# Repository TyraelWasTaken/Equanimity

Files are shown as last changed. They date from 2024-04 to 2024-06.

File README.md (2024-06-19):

# Equanimity
## Equanimity is a 65%, gasket mounted, alice style keyboard with a knob.

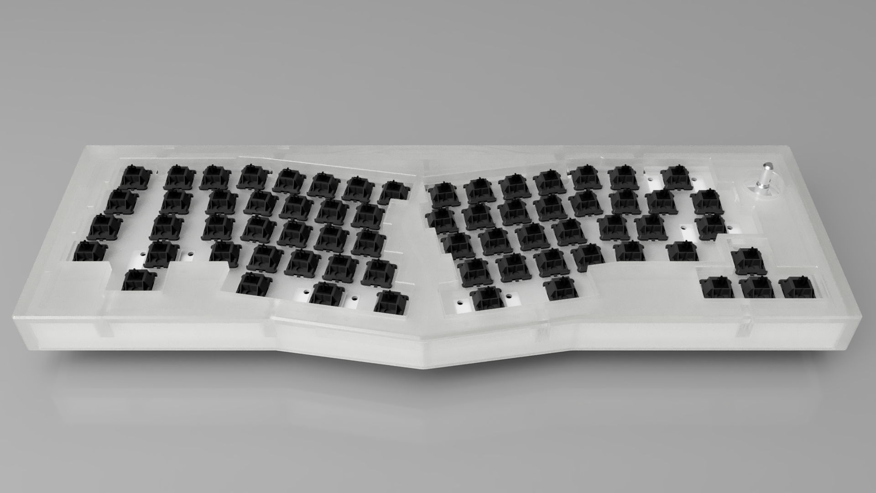
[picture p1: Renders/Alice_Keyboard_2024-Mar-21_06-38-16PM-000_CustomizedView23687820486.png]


There were no design goals for the project, it was simply what I wanted to see in a keyboard.

It is fully Open-Source, all files I have used to make my own I have published for everyone else to enjoy.

Firmware wise, the qmk build *should* be functional, and I am actively working on trying to publish a successful via build.

Equanimity uses cherry switches with kailh hotswap sockets, and the standard EC11 (although an EC12 should work just fine).
Also, the project uses a C series unified daughterboard with JST connectors.

The "symbol" for the equanimity is a water lily.

If you wish to build this or have any inquiries please contact me via discord and I will help you with the project.

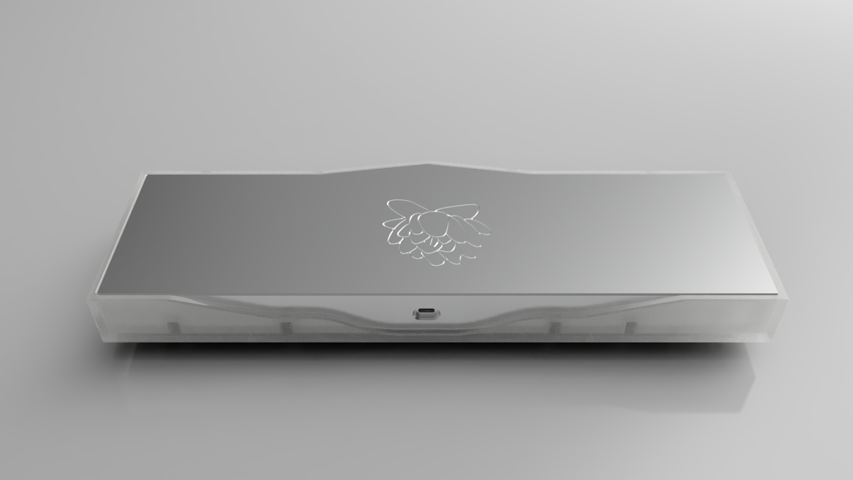
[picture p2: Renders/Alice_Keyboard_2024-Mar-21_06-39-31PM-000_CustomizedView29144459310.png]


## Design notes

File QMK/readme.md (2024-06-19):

# equanimity

equanimity

Arisu-ish Alice keyboard with an EC11 and some accent keys, staggered.

* Keyboard Maintainer: [TyraelWasTaken](https://github.com/TyraelWasTaken)
* Hardware Supported: *UDB C3 or greater with Equanimity PCB, no other PCBs are supported for the case*
* Hardware Availability: *If you wish to build this, all files are available here: https://github.com/TyraelWasTaken/Equanimity*

Make example for this keyboard (after setting up your build environment):

    make TyraelWasTaken/equanimity:default

Flashing example for this keyboard:

    make TyraelWasTaken/equanimity:default:flash

See the [build environment setup](https://docs.qmk.fm/#/getting_started_build_tools) and the [make instructions](https://docs.qmk.fm/#/getting_started_make_guide) for more information. Brand new to QMK? Start with our [Complete Newbs Guide](https://docs.qmk.fm/#/newbs).

## Bootloader

Enter the bootloader in 3 ways:

* **Bootmagic reset**: Hold down the key at (0,0) in the matrix (set as Delete by default) and plug in the keyboard
* **Physical reset button**: Press both the Top and Bottom buttons at the same time
* **Keycode in layout**: Press the key mapped to `RESET` if it is available (this has not been mapped by default)

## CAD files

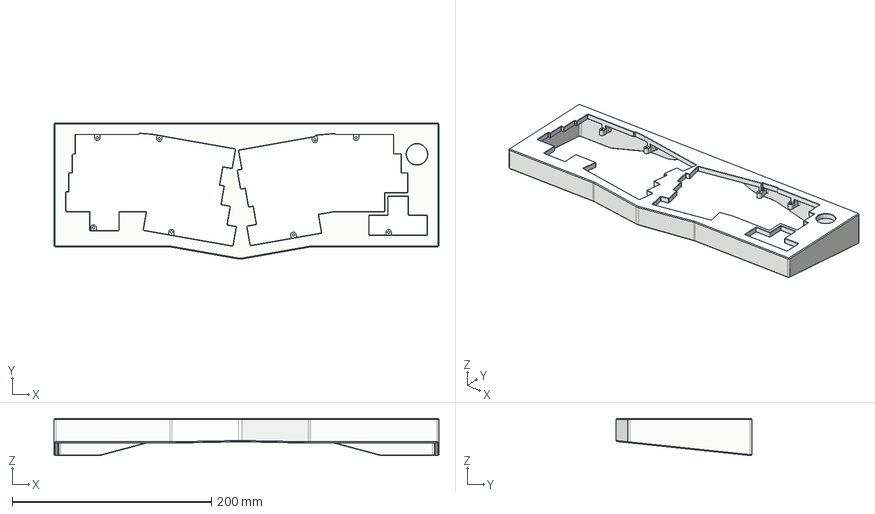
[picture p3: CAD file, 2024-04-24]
Case/Top Case.step
386.9 x 137.1 x 37.6 mm

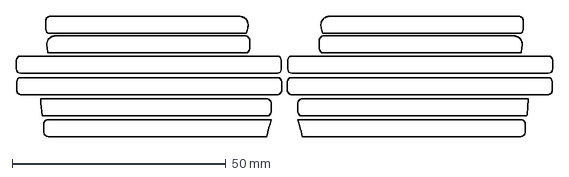
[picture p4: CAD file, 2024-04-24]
Gaskets/Gaskets.dxf
125.5 x 28.1 mm

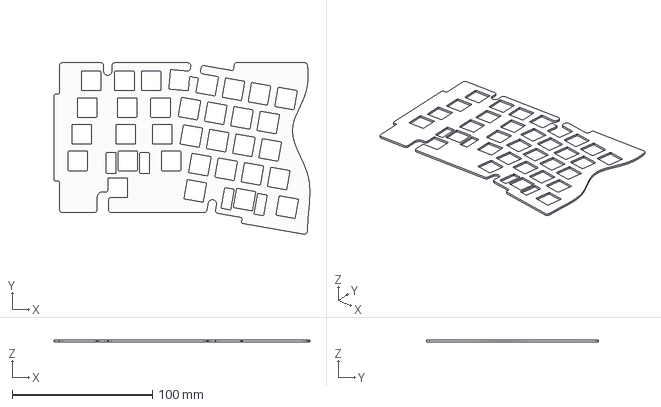
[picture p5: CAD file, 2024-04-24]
Plates/Left Plate.step
182.8 x 122.5 x 1.50 mm

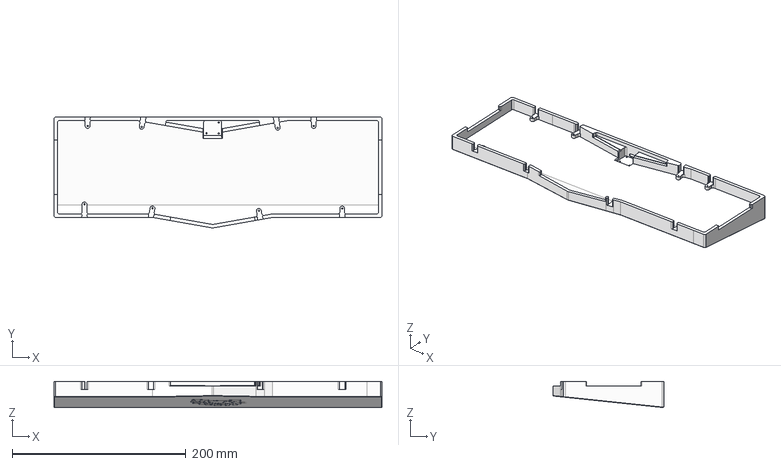
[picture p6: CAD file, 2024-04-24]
Case/Bottom Case.step
377.4 x 127.6 x 30.1 mm

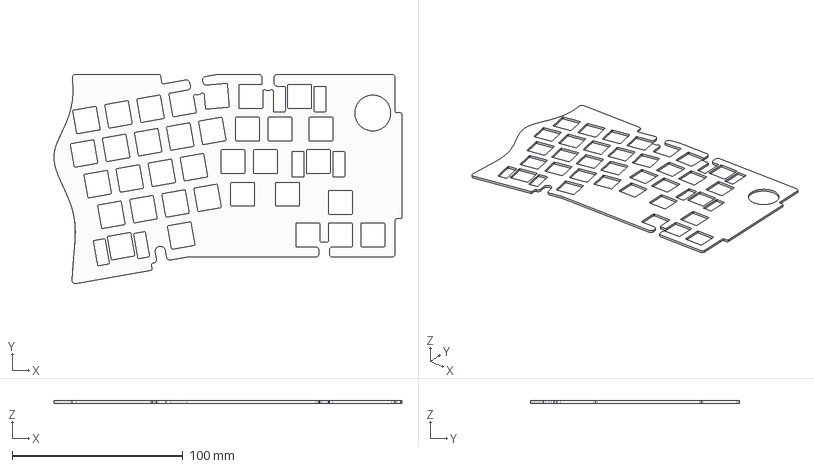
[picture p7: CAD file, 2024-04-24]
Plates/Right plate.step
203.6 x 122.5 x 1.50 mm

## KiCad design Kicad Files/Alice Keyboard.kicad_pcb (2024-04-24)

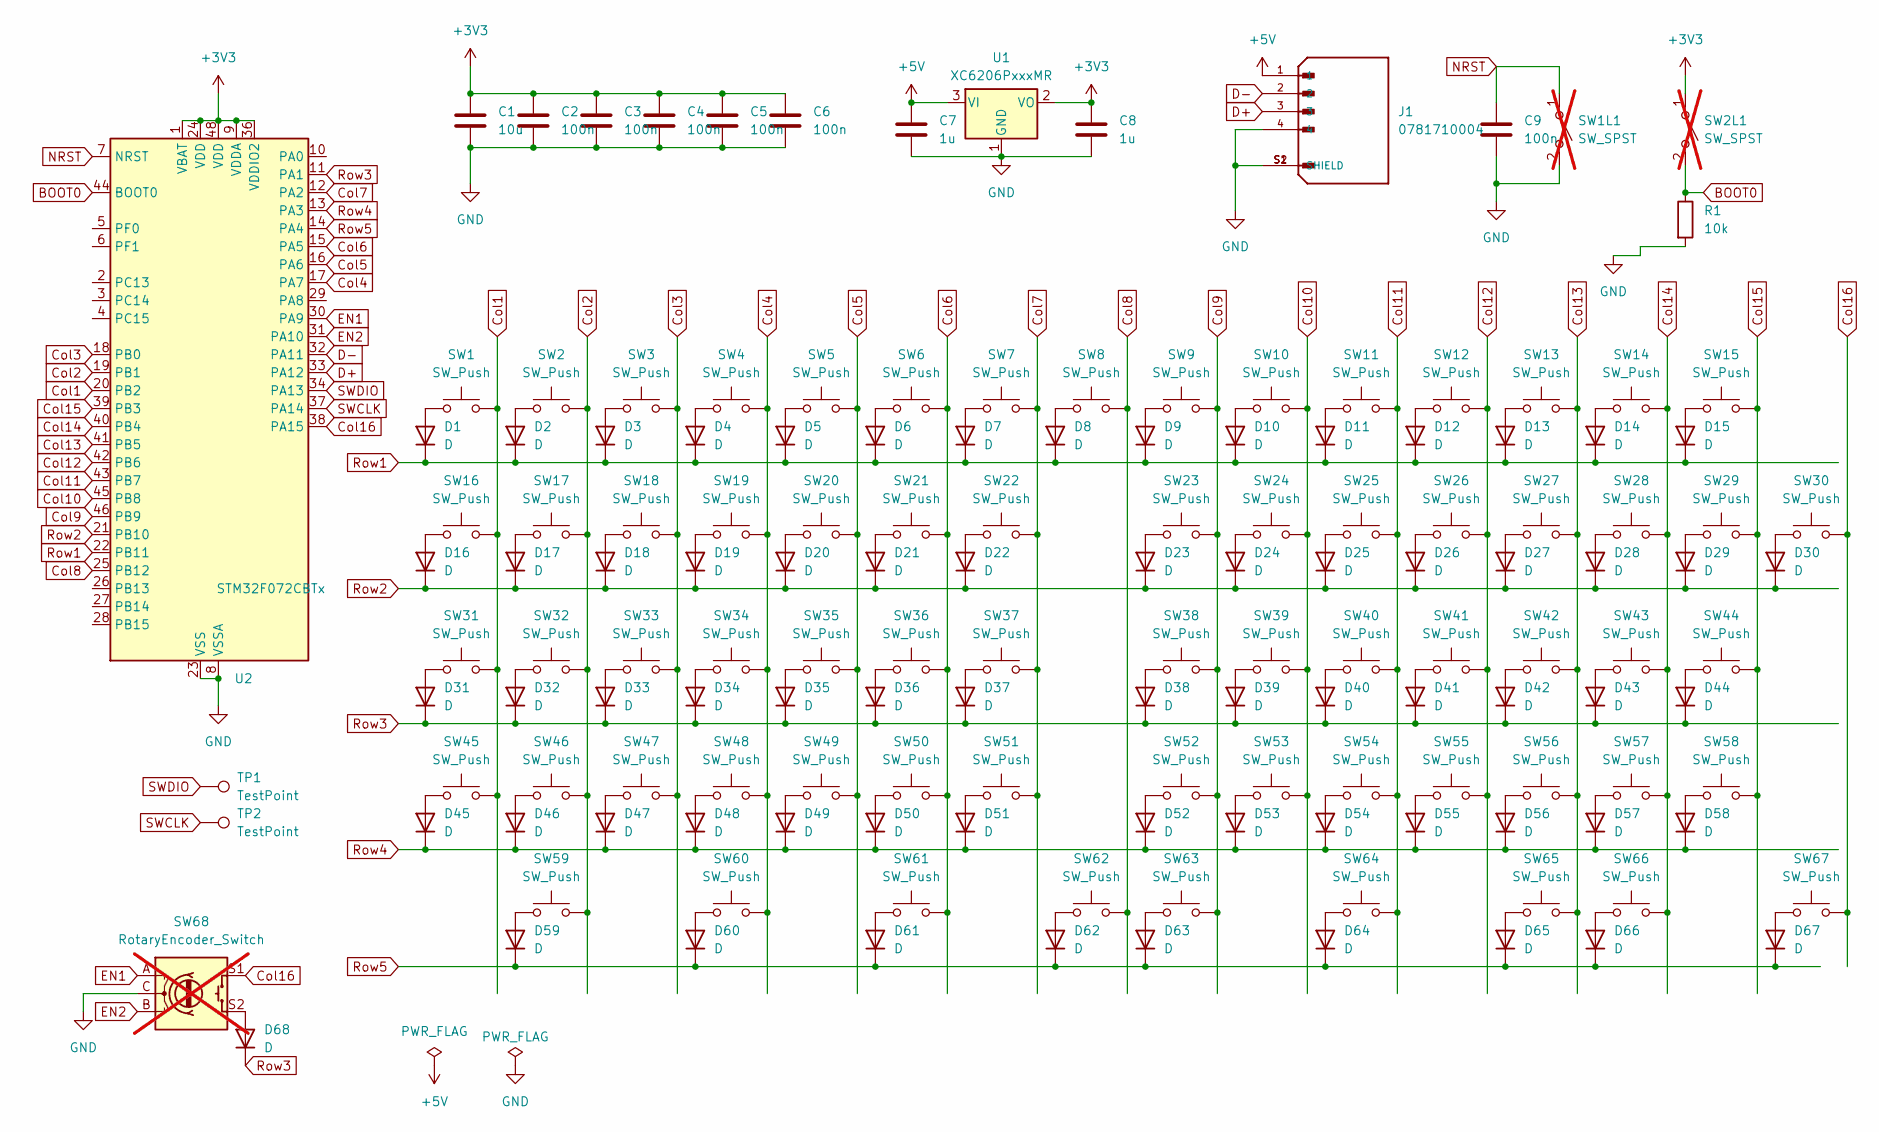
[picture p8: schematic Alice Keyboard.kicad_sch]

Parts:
C1: 10u; C_0805_2012Metric_Pad1.18x1.45mm_HandSolder
C2, C3, C4, C5, C6, C9: 100n; C_0603_1608Metric
C7, C8: 1u; C_0805_2012Metric_Pad1.18x1.45mm_HandSolder
D1, D2, D3, D4, D5, D6, D7, D8, D9, D10, D11, D12, D13, D14, D15, D16, D17, D18, D19, D20, D21, D22, D23, D24, D25, D26, D27, D28, D29, D30, D31, D32, D33, D34, D35, D36, D37, D38, D39, D40, D41, D42, D43, D44, D45, D46, D47, D48, D49, D50, D51, D52, D53, D54, D55, D56, D57, D58, D59, D60, D61, D62, D63, D64, D65, D66, D67, D68: D; D_SOD-123
J1: 0781710004; SM04B-SRSS-TB(LF)(SN); PARTREV G
R1: 10k; R_0805_2012Metric_Pad1.20x1.40mm_HandSolder
SW1, SW2, SW3, SW4, SW5, SW6, SW7, SW8, SW9, SW10, SW11, SW12, SW13, SW14, SW16, SW18, SW19, SW20, SW21, SW22, SW23, SW24, SW25, SW26, SW27, SW28, SW29, SW31, SW33, SW34, SW35, SW36, SW37, SW38, SW39, SW40, SW41, SW42, SW43, SW45, SW47, SW48, SW49, SW50, SW51, SW52, SW53, SW54, SW55, SW56, SW58, SW62, SW65, SW66, SW67: SW_Push; MX-Hotswap-1U
SW1L1, SW2L1: SW_SPST; SW_SPST_SKQG_WithStem; not fitted
SW15: SW_Push; MX-Hotswap-2U
SW17, SW30, SW59, SW60, SW64: SW_Push; MX-Hotswap-1.5U
SW32, SW57: SW_Push; MX-Hotswap-1.75U
SW44, SW46, SW61, SW63: SW_Push; MX-Hotswap-2.25U
SW68: RotaryEncoder_Switch; RotaryEncoder_Alps_EC11E-Switch_Vertical_H20mm; not fitted
TP1, TP2: TestPoint; Pin_D0.7mm_L6.5mm_W1.8mm_FlatFork
U1: XC6206PxxxMR; SOT-23-3
U2: STM32F072CBTx; LQFP-48_7x7mm_P0.5mm

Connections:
+3V3: C1.1, C2.1, C3.1, C4.1, C5.1, C6.1, C8.1, SW2L1.1 (A), U1.2 (VO), U2.1 (VBAT), U2.9 (VDDA), U2.24 (VDD), U2.36 (VDDIO2), U2.48 (VDD)
+5V: C7.1, J1.1, U1.3 (VI)
BOOT0: R1.1, SW2L1.2 (B), U2.44 (BOOT0)
Col1: SW1.2, SW16.2, SW31.2, SW45.2, U2.20 (PB2)
Col2: SW2.2, SW17.2, SW32.2, SW46.2, SW59.2, U2.19 (PB1)
Col3: SW3.2, SW18.2, SW33.2, SW47.2, U2.18 (PB0)
Col4: SW4.2, SW19.2, SW34.2, SW48.2, SW60.2, U2.17 (PA7)
Col5: SW5.2, SW20.2, SW35.2, SW49.2, U2.16 (PA6)
Col6: SW6.2, SW21.2, SW36.2, SW50.2, SW61.2, U2.15 (PA5)
Col7: SW7.2, SW22.2, SW37.2, SW51.2, U2.12 (PA2)
Col8: SW8.2, SW62.2, U2.25 (PB12)
Col9: SW9.2, SW23.2, SW38.2, SW52.2, SW63.2, U2.46 (PB9)
Col10: SW10.2, SW24.2, SW39.2, SW53.2, U2.45 (PB8)
Col11: SW11.2, SW25.2, SW40.2, SW54.2, SW64.2, U2.43 (PB7)
Col12: SW12.2, SW26.2, SW41.2, SW55.2, U2.42 (PB6)
Col13: SW13.2, SW27.2, SW42.2, SW56.2, SW65.2, U2.41 (PB5)
Col14: SW14.2, SW28.2, SW43.2, SW57.2, SW66.2, U2.40 (PB4)
Col15: SW15.2, SW29.2, SW44.2, SW58.2, U2.39 (PB3)
Col16: SW30.2, SW67.2, SW68.S1, U2.38 (PA15)
D+: J1.3, U2.33 (PA12)
D-: J1.2, U2.32 (PA11)
EN1: SW68.A, U2.30 (PA9)
EN2: SW68.B, U2.31 (PA10)
GND: C1.2, C2.2, C3.2, C4.2, C5.2, C6.2, C7.2, C8.2, C9.2, J1.4, J1.S1 (SHIELD), J1.S2 (SHIELD), R1.2, SW1L1.2 (B), SW68.C, U1.1 (GND), U2.8 (VSSA), U2.23 (VSS), U2.35 (VSS), U2.47 (VSS)
NRST: C9.1, SW1L1.1 (A), U2.7 (NRST)
unnamed: D1.2 (A), SW1.1
unnamed: D2.2 (A), SW2.1
unnamed: D3.2 (A), SW3.1
unnamed: D4.2 (A), SW4.1
unnamed: D5.2 (A), SW5.1
unnamed: D6.2 (A), SW6.1
unnamed: D7.2 (A), SW7.1
unnamed: D8.2 (A), SW8.1
unnamed: D9.2 (A), SW9.1
unnamed: D10.2 (A), SW10.1
unnamed: D11.2 (A), SW11.1
unnamed: D12.2 (A), SW12.1
unnamed: D13.2 (A), SW13.1
unnamed: D14.2 (A), SW14.1
unnamed: D15.2 (A), SW15.1
unnamed: D16.2 (A), SW16.1
unnamed: D17.2 (A), SW17.1
unnamed: D18.2 (A), SW18.1
unnamed: D19.2 (A), SW19.1
unnamed: D20.2 (A), SW20.1
unnamed: D21.2 (A), SW21.1
unnamed: D22.2 (A), SW22.1
unnamed: D23.2 (A), SW23.1
unnamed: D24.2 (A), SW24.1
unnamed: D25.2 (A), SW25.1
unnamed: D26.2 (A), SW26.1
unnamed: D27.2 (A), SW27.1
unnamed: D28.2 (A), SW28.1
unnamed: D29.2 (A), SW29.1
unnamed: D30.2 (A), SW30.1
unnamed: D31.2 (A), SW31.1
unnamed: D32.2 (A), SW32.1
unnamed: D33.2 (A), SW33.1
unnamed: D34.2 (A), SW34.1
unnamed: D35.2 (A), SW35.1
unnamed: D36.2 (A), SW36.1
unnamed: D37.2 (A), SW37.1
unnamed: D38.2 (A), SW38.1
unnamed: D39.2 (A), SW39.1
unnamed: D40.2 (A), SW40.1
unnamed: D41.2 (A), SW41.1
unnamed: D42.2 (A), SW42.1
unnamed: D43.2 (A), SW43.1
unnamed: D44.2 (A), SW44.1
unnamed: D45.2 (A), SW45.1
unnamed: D46.2 (A), SW46.1
unnamed: D47.2 (A), SW47.1
unnamed: D48.2 (A), SW48.1
unnamed: D49.2 (A), SW49.1
unnamed: D50.2 (A), SW50.1
unnamed: D51.2 (A), SW51.1
unnamed: D52.2 (A), SW52.1
unnamed: D53.2 (A), SW53.1
unnamed: D54.2 (A), SW54.1
unnamed: D55.2 (A), SW55.1
unnamed: D56.2 (A), SW56.1
unnamed: D57.2 (A), SW57.1
unnamed: D58.2 (A), SW58.1
unnamed: D59.2 (A), SW59.1
unnamed: D60.2 (A), SW60.1
unnamed: D61.2 (A), SW61.1
unnamed: D62.2 (A), SW62.1
unnamed: D63.2 (A), SW63.1
unnamed: D64.2 (A), SW64.1
unnamed: D65.2 (A), SW65.1
unnamed: D66.2 (A), SW66.1
unnamed: D67.2 (A), SW67.1
unnamed: D68.2 (A), SW68.S2
Row1: D1.1 (K), D2.1 (K), D3.1 (K), D4.1 (K), D5.1 (K), D6.1 (K), D7.1 (K), D8.1 (K), D9.1 (K), D10.1 (K), D11.1 (K), D12.1 (K), D13.1 (K), D14.1 (K), D15.1 (K), U2.22 (PB11)
Row2: D16.1 (K), D17.1 (K), D18.1 (K), D19.1 (K), D20.1 (K), D21.1 (K), D22.1 (K), D23.1 (K), D24.1 (K), D25.1 (K), D26.1 (K), D27.1 (K), D28.1 (K), D29.1 (K), D30.1 (K), U2.21 (PB10)
Row3: D31.1 (K), D32.1 (K), D33.1 (K), D34.1 (K), D35.1 (K), D36.1 (K), D37.1 (K), D38.1 (K), D39.1 (K), D40.1 (K), D41.1 (K), D42.1 (K), D43.1 (K), D44.1 (K), D68.1 (K), U2.11 (PA1)
Row4: D45.1 (K), D46.1 (K), D47.1 (K), D48.1 (K), D49.1 (K), D50.1 (K), D51.1 (K), D52.1 (K), D53.1 (K), D54.1 (K), D55.1 (K), D56.1 (K), D57.1 (K), D58.1 (K), U2.13 (PA3)
Row5: D59.1 (K), D60.1 (K), D61.1 (K), D62.1 (K), D63.1 (K), D64.1 (K), D65.1 (K), D66.1 (K), D67.1 (K), U2.14 (PA4)
SWCLK: TP2.1, U2.37 (PA14)
SWDIO: TP1.1, U2.34 (PA13)

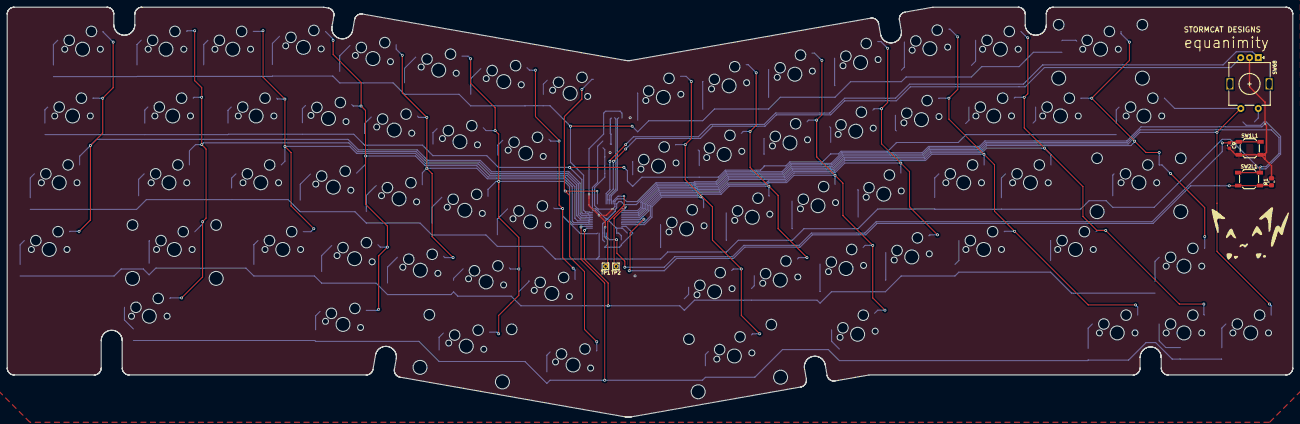
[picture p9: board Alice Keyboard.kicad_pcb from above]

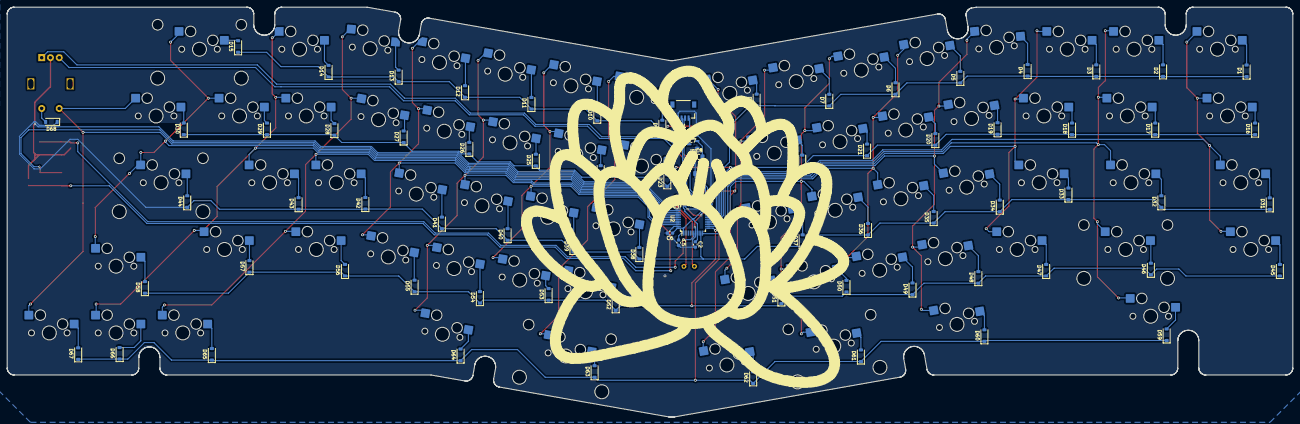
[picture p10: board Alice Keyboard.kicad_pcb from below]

Board: 2 copper layers, 366.9 x 117.0 mm, 153 parts (79 on the bottom side), 100 nets.

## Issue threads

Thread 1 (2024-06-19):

Plate Tolerance too tight

TyraelWasTaken, 2024-06-19:
At one point the plate scrapes with the case (bottom left screw area) - if it has been 3d printed, this should not be an issue with laser cut plates and can be easily rectified with a bit of glue.

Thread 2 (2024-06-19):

Encoder off center

TyraelWasTaken, 2024-06-19:
Encoder is a few millimeters off center from the case cut out, does not interfere with a knob.

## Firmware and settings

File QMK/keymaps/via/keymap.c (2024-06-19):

// Copyright 2024 TyraelWasTaken (@TyraelWasTaken)
// SPDX-License-Identifier: GPL-2.0-or-later

#include QMK_KEYBOARD_H

enum layer_names {
    _BL,
    _FL,
};

const uint16_t PROGMEM keymaps[][MATRIX_ROWS][MATRIX_COLS] = {

    [_BL] = LAYOUT(
        KC_DELETE, KC_GRAVE, KC_1, KC_2, KC_3, KC_4, KC_5, KC_6, KC_7, KC_8, KC_9, KC_0, KC_MINUS, KC_EQUAL, KC_BACKSPACE,
        KC_HOME, KC_TAB, KC_Q, KC_W, KC_E, KC_R, KC_T, KC_Y, KC_U, KC_I, KC_O, KC_P, KC_LBRC, KC_RBRC, KC_BSLS,
        KC_PGUP, KC_CAPS_LOCK, KC_A, KC_S, KC_D, KC_F, KC_G, KC_H, KC_J, KC_K, KC_L, KC_SCLN, KC_QUOTE, KC_ENT, KC_MEDIA_PLAY_PAUSE,
        KC_PGDN, KC_LSFT, KC_Z, KC_X, KC_C, KC_V, KC_B, KC_N, KC_M, KC_COMMA, KC_DOT, KC_SLASH, KC_RSFT, KC_UP,
        KC_LCTL, KC_LGUI, KC_SPC, MO(_FL), KC_SPC, KC_LALT, KC_LEFT, KC_DOWN, KC_RGHT
    ),

    [_FL] = LAYOUT(
        KC_TRNS, KC_TRNS, KC_F1, KC_F2, KC_F3, KC_F4, KC_F5, KC_F6, KC_F7, KC_F8, KC_F9, KC_F10, KC_F11, KC_F12, KC_TRNS,
        KC_TRNS, KC_TRNS, KC_TRNS, KC_TRNS, KC_TRNS, KC_TRNS, KC_TRNS, KC_TRNS, KC_TRNS, KC_TRNS, KC_TRNS, KC_TRNS, KC_TRNS, KC_TRNS, KC_TRNS,
        KC_TRNS, KC_TRNS, KC_TRNS, KC_TRNS, KC_TRNS, KC_TRNS, KC_TRNS, KC_TRNS, KC_TRNS, KC_TRNS, KC_TRNS, KC_TRNS, KC_TRNS, KC_TRNS, KC_TRNS,
        KC_TRNS, KC_TRNS, KC_TRNS, KC_TRNS, KC_TRNS, KC_TRNS, KC_TRNS, KC_TRNS, KC_TRNS, KC_TRNS, KC_TRNS, KC_TRNS, KC_TRNS, KC_PGUP,
        KC_TRNS, KC_TRNS, KC_TRNS, KC_TRNS, KC_TRNS, KC_TRNS, KC_HOME, KC_PGDN, KC_END
    )  
};

#ifdef ENCODER_MAP_ENABLE
    const uint16_t PROGMEM encoder_map[][NUM_ENCODERS][NUM_DIRECTIONS] = {
        [_BL] = { ENCODER_CCW_CW(KC_VOLD, KC_VOLU) },
        [_FL] = { ENCODER_CCW_CW(KC_VOLD, KC_VOLU) },
    };
#endif

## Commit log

2024-06-19 Upload Encoder files
2024-06-19 Update kicad files
    The old files had an issue with the D+ and D- lines being flipped the wrong way, this has rectified this.
    [Alice Keyboard depr.kicad_pcb, Alice Keyboard.kicad_sch]
2024-06-19 Update QMK files
    New files add support for VIA and fixes issues with encoders and keys not functioning.
    [keymap.c]
